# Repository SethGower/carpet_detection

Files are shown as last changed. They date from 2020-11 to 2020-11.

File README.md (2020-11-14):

# Carpet Detection PCB for CMPE-460 NXP Cup Autonomous Vehicle race

This is the carpet detection circuit I designed for the NXP/Freescale Cup race.
The purpose of it is to add hardware carpet detection to the car, by using the
OPB745 opto-isolator sensor to detect if the car is on the track. If the sensor
is above the carpet, the output of the amplifier will be high, and the
micro-controller will be able to read this on a GPIO pin. If it is on the
carpet, the output of the amplifier will be low, providing a voltage drop across
the LED, lighting up the LED (red). 

Part was designed using KiCAD.

## Hardware
### Schematic
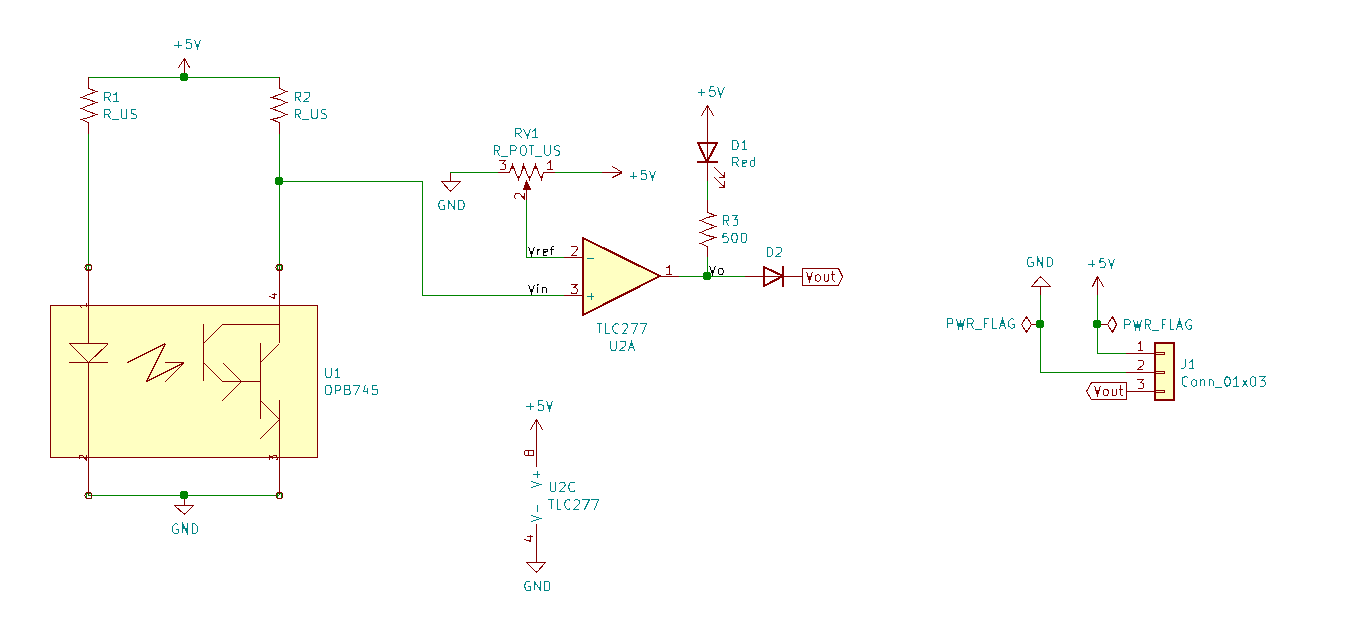
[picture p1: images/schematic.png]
KiCAD Schematic


### PCB
Front | Back
:-----:|:-----:
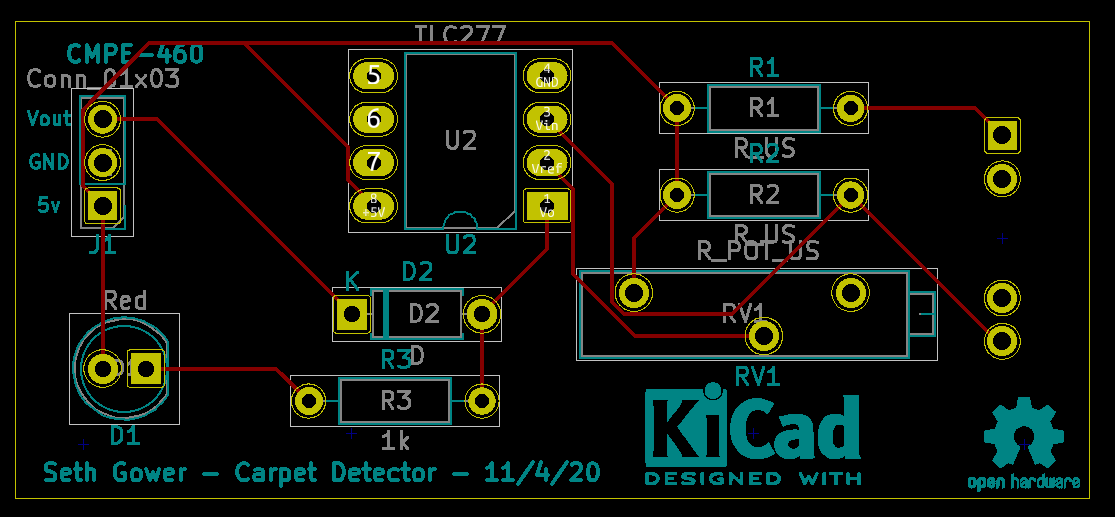
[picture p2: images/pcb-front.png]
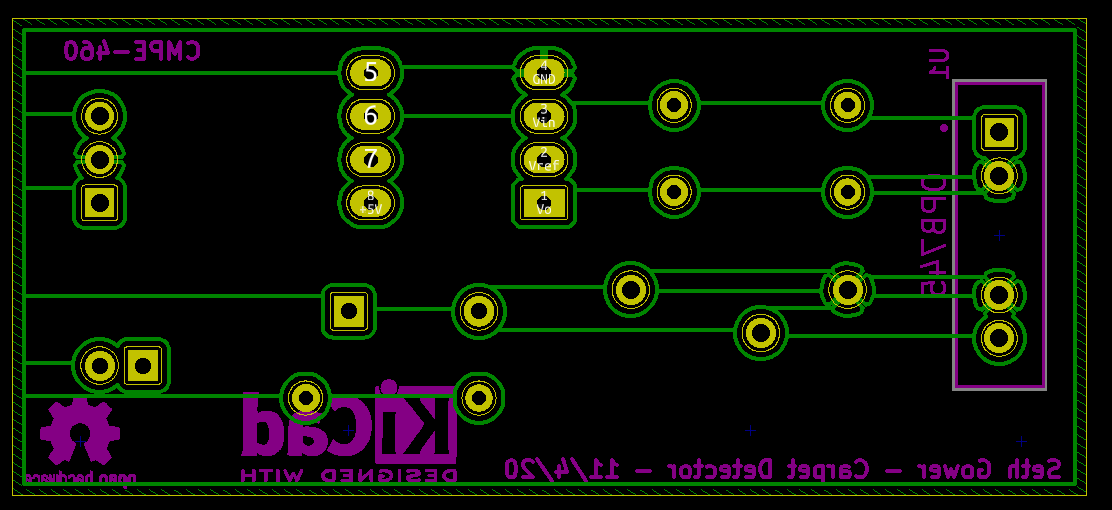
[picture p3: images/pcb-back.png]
 | 

3D View
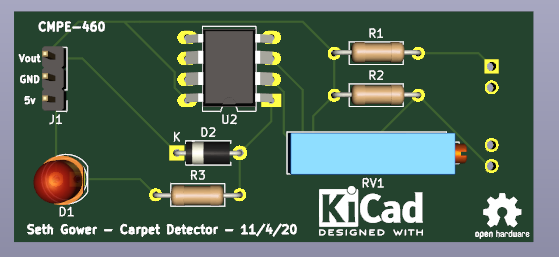
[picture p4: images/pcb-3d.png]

Idea inspired by a suggestion from Louis Beato

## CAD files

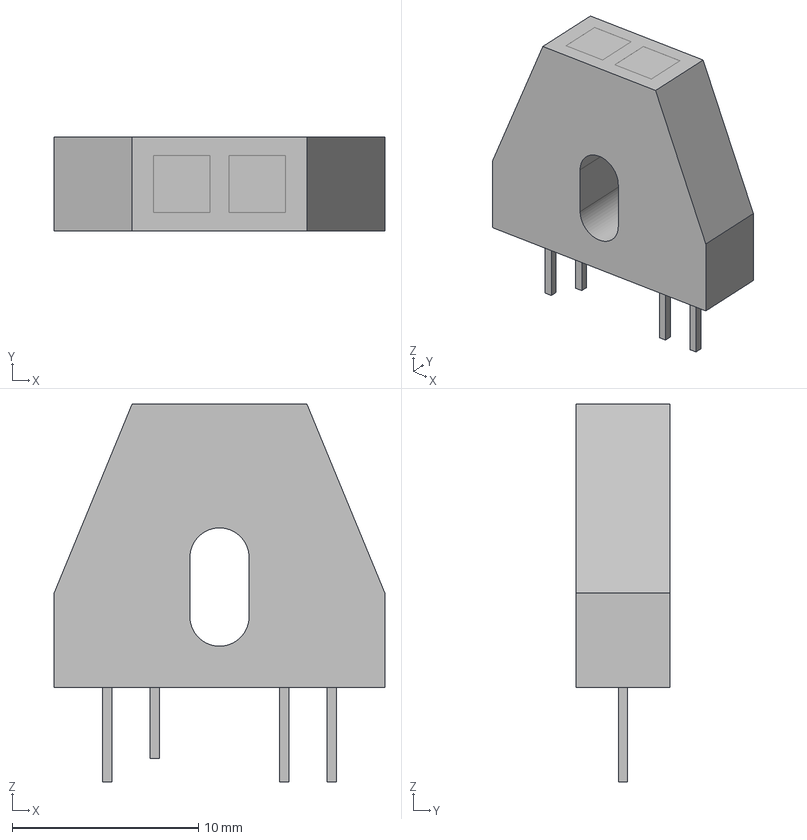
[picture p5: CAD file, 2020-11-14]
schematics/carpet_detection/opb745/eec.models/TT_Electronics_-_OPB745.step
17.8 x 5.08 x 20.3 mm

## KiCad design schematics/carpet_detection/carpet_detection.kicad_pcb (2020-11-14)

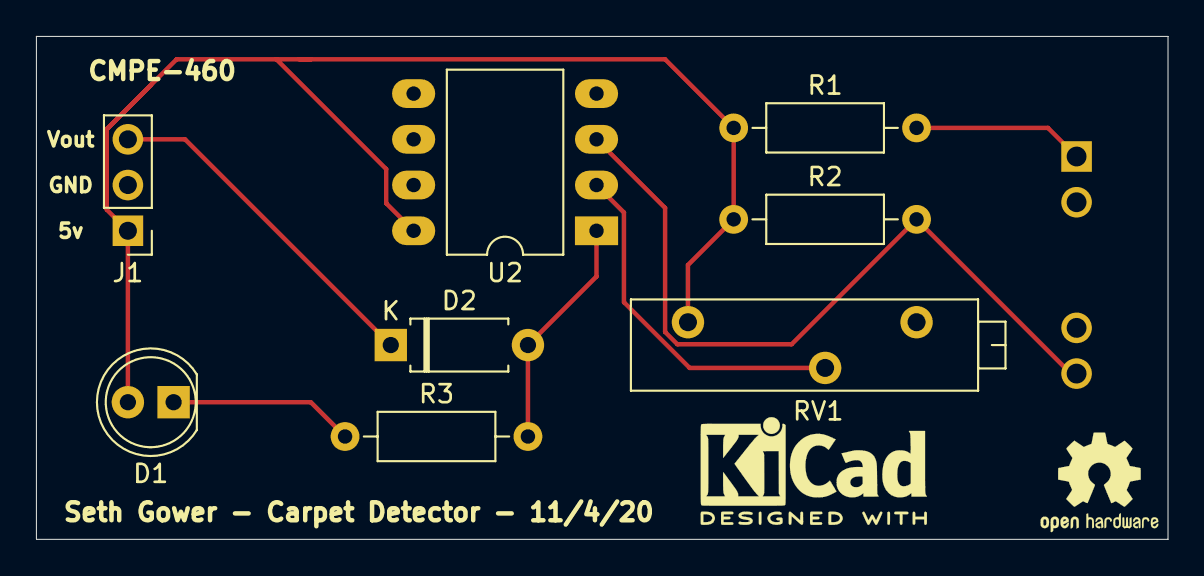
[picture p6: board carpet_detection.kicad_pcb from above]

Board: 2 copper layers, 62.9 x 27.9 mm, 9 parts (1 on the bottom side), 8 nets.

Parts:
D1: Red; LED_D5.0mm
D2: D; D_A-405_P7.62mm_Horizontal
J1: Conn_01x03; PinHeader_1x03_P2.54mm_Vertical
R1, R2: R_US; R_Axial_DIN0207_L6.3mm_D2.5mm_P10.16mm_Horizontal
R3: 1k; R_Axial_DIN0207_L6.3mm_D2.5mm_P10.16mm_Horizontal
RV1: R_POT_US; Potentiometer_Bourns_3006P_Horizontal
U1: OPB745; TT_Electronics-OPB745-0
U2: TLC277; DIP-8_W10.16mm_LongPads

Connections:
+5V: D1.2, J1.1, R1.1, R2.1, RV1.1, U2.8
/Vin: R2.2, U1.4, U2.3
/Vo: D2.2, R3.2, U2.1
/Vref: RV1.2, U2.2
GND: J1.2, RV1.3, U1.2, U1.3, U2.4
unnamed: D1.1, R3.1
unnamed: R1.2, U1.1
Vout: D2.1, J1.3

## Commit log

2020-11-14 Adds Schematic for carpet detection
    [TT_Electronics_-_OPB745.step, carpet_detection.kicad_pcb, carpet_detection.sch]
2020-11-14 updates schemaitic to use trimpot for Vref
    [carpet_detection.kicad_pcb, carpet_detection.sch]
2020-11-14 Adds LEDS to the carpet detector
    [carpet_detection.kicad_pcb, carpet_detection.sch]
2020-11-14 Removes Green LED, moves OPB745 to bottom, everything else to top
    [carpet_detection.kicad_pcb, carpet_detection.sch]
2020-11-14 Final revision of the PCB. Ordered on OSH Park
    [carpet_detection.kicad_pcb, carpet_detection.sch]
2020-11-14 Actually finishes the PCB.
    [carpet_detection.kicad_pcb, carpet_detection.sch]
